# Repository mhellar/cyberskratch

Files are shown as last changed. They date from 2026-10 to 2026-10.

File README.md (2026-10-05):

# CYBERSKRATCH

**A robot DJ on an ESP32-S3.** SAM (the 1982 Software Automatic Mouth) speaks words onto a turntable deck you
scratch, either tempo-synced by holding a pad or by hand with the knob. It also has a Speak & Spell mouth (Talkie LPC) you can bend and freeze, a
hip-hop drum machine, a 16-step sequencer and a rack of voice effects. It runs on a 4x4 keypad, one knob, a
128x128 OLED and a small speaker.

**New in this release:**
- **3D viz engine.** A small polygon renderer (flat-shaded solids, wireframes, painter's sort, glitch post-FX,
  Bayer dithering) drives a VJ view that plays along with the music, and a 3D intro film.
- **Laser-cut case.** A minimal top and bottom plate in 3 mm acrylic, with an engraved legend.

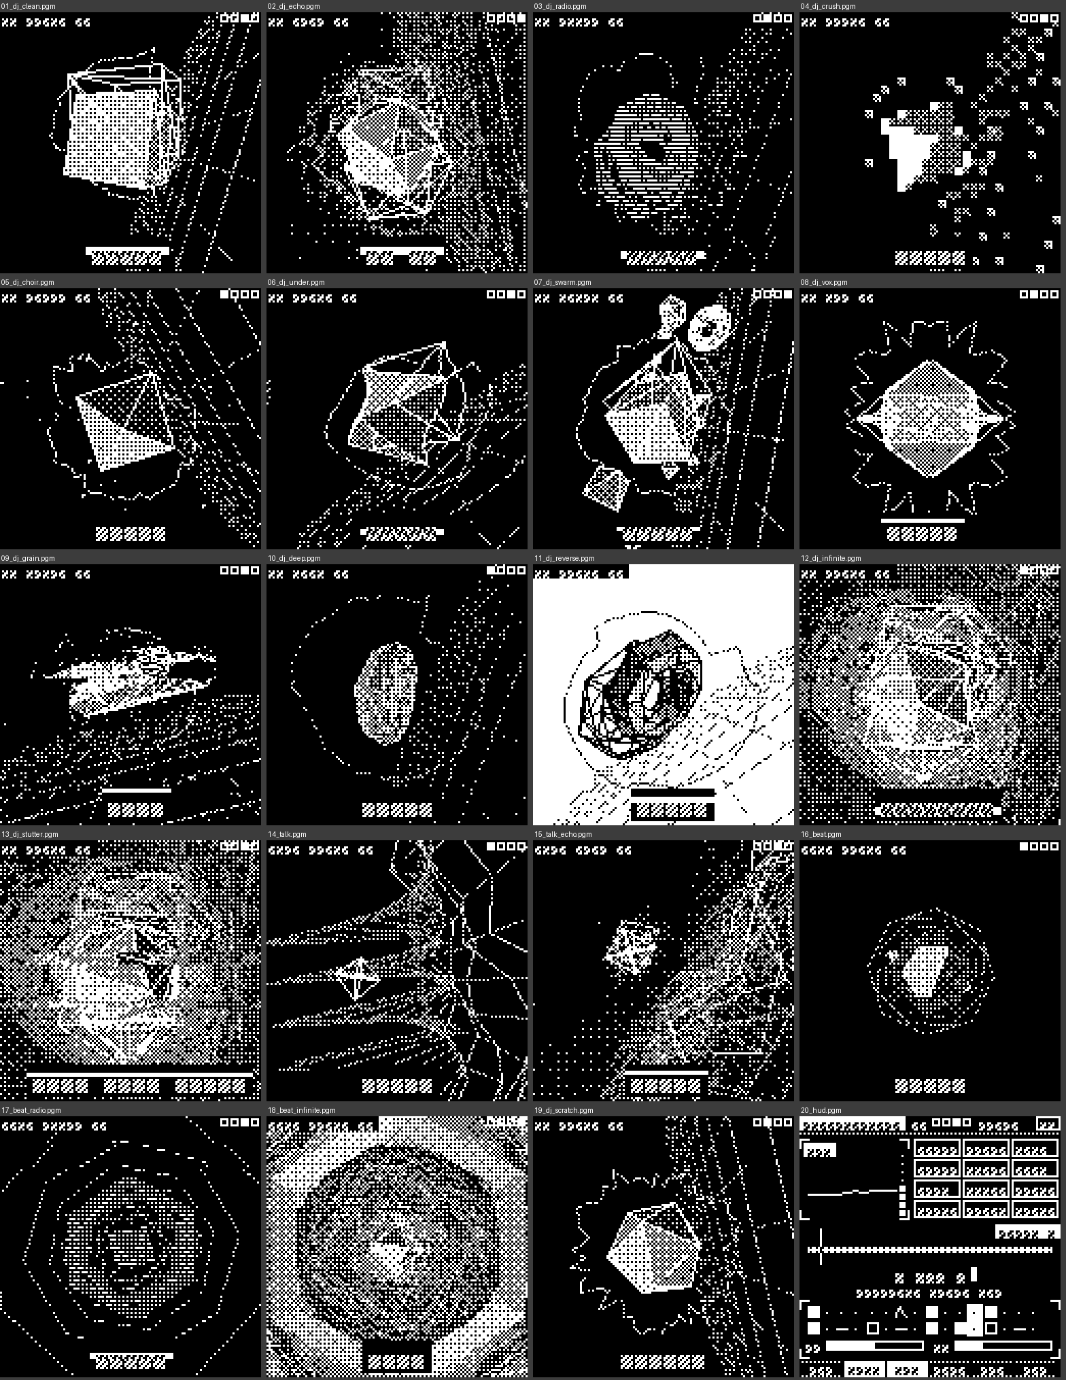
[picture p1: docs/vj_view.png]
VJ view, every mode and FX


| 3D intro | Laser-cut case |
|---|---|
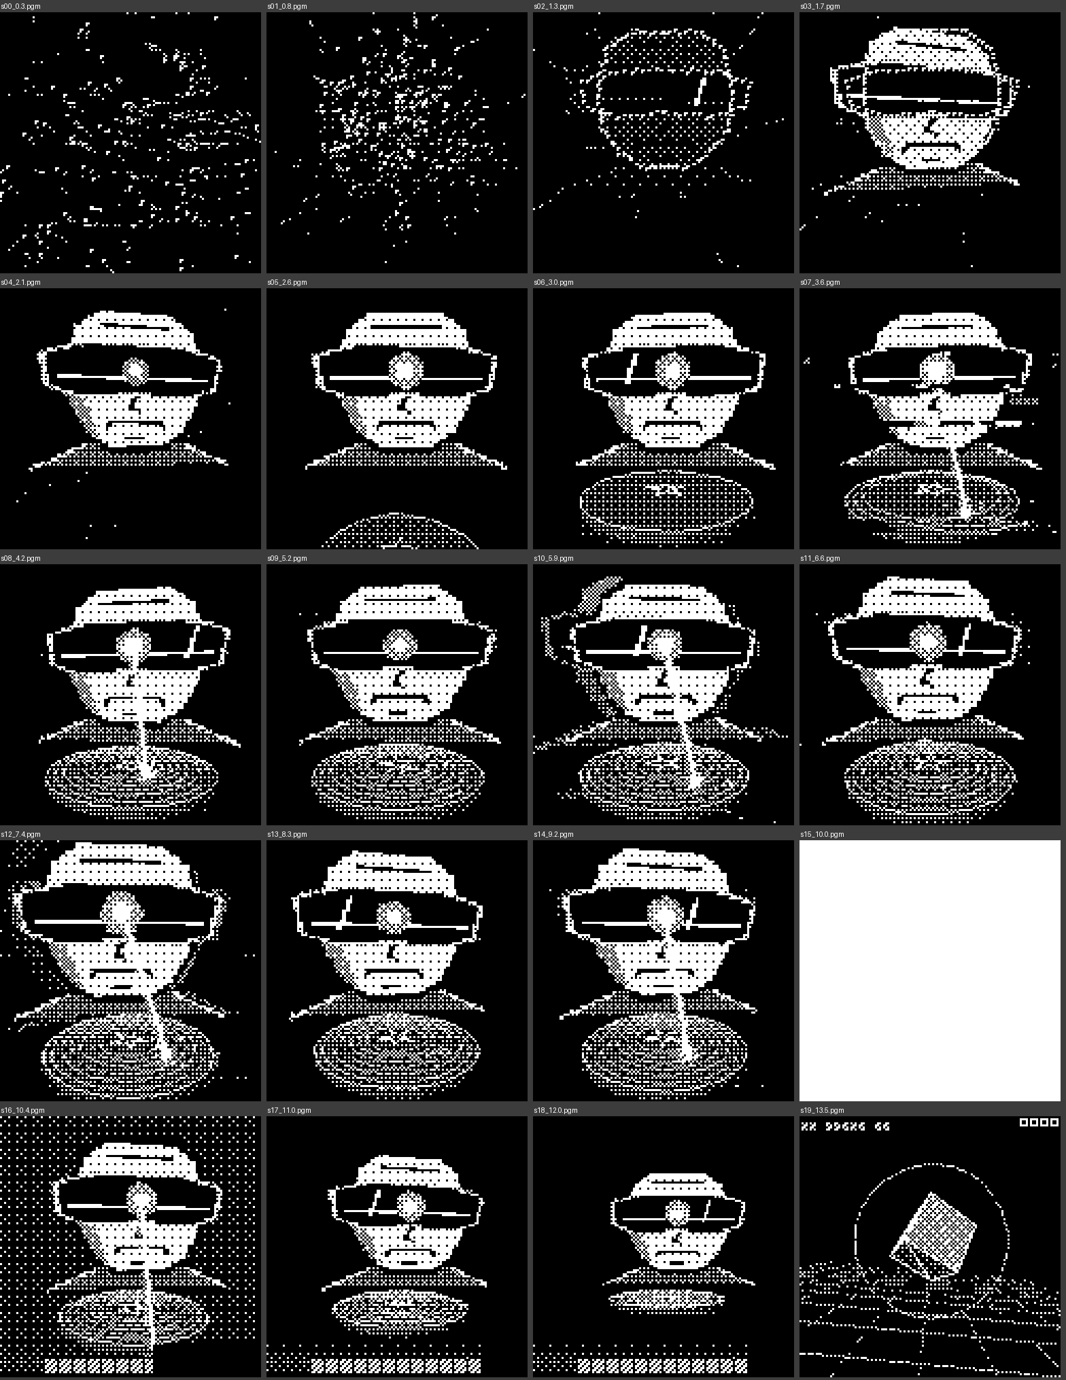
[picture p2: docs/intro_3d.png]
intro
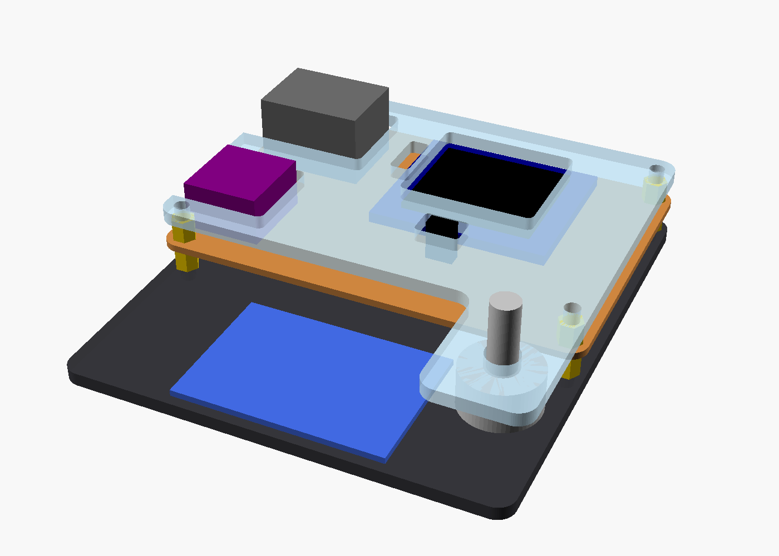
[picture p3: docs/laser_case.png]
case
|  |  |

## What's in here

| Folder | Contents |
|---|---|
| `firmware/cyberskratch_3d/` | The Arduino sketch, with SAM's C core and the Talkie vocabularies bundled alongside |
| `firmware/cyberskratch_3d/host_sim/` | Desktop simulator: runs the real audio engine with g++ and saves VJ frames (see its README) |
| `hardware/laser_case/` | Minimal acrylic case: top plate (cut + engrave), bottom plate, OpenSCAD source, build notes |
| `docs/MANUAL.md` | How to play it |

The board itself (keypad synth rev B, single-sided, CNC-milled) is in the
**blasteroid-megasynth** repo under `hardware/`. CyberSkratch runs on the same board.

## Parts

| Part | Notes |
|---|---|
| ESP32-S3 **SuperMini** with **PSRAM** (4 MB flash / 2 MB PSRAM) | on 2x 1x9 female headers |
| MAX98357A I2S amp breakout + small 4-8 ohm speaker | VIN on 5 V |
| 1.5" 128x128 OLED, **SH1107**, I2C | VCC GND SCL SDA |
| 4x4 tact keypad module (passive matrix, e.g. QYF-JP01) | hangs off the front edge on edge pads |
| 10k pot | on wires, mounted in the case's wing |
| optional TRRS breakout | headphones, wired off the amp |

## Pinout (rev A / rev B board)

| Function | GPIO |
|---|---|
| OLED SDA / SCL | 9 / 8 |
| Amp DIN / BCLK / LRC | 43 (TX) / 44 (RX) / 1 |
| Keypad rows R1-R4 / columns C1-C4 | 2 3 4 5 / 6 7 13 12 |
| Pot wiper / pot high leg | 10 / 11 (driven HIGH as the pot's supply), low leg to GND |

For the full-size DevKitC board (rev C), set `#define BOARD_REV_C 1` at the top of the sketch.
The amp uses the TX/RX pins, so **USB CDC On Boot must be Enabled** (serial goes over native USB).

## Build the firmware

1. Arduino IDE (or arduino-cli) with the **ESP32 core 3.x** and the **U8g2** library.
2. Board settings: **ESP32S3 Dev Module**, **USB CDC On Boot: Enabled**, **PSRAM: enabled**
   (a DevKitC-1 N8R8 needs PSRAM: OPI).
   arduino-cli FQBN: `esp32:esp32:esp32s3:CDCOnBoot=cdc,PSRAM=enabled`
3. Open `firmware/cyberskratch_3d/cyberskratch_3d.ino` and upload.

## Laser-cut case

Two pieces of 3 mm acrylic, cut on a CO2 laser. The top plate sits 5 mm above the board on M3 standoffs, with
cut-outs around the tall parts and a plain window over the OLED. The pot sits on a wing beside the keypad. The board
stands on 6 mm standoffs on the bottom plate. `hardware/laser_case/README.txt` has the parts list and laser
settings. `top_plate_LASER.svg` is cut + engrave in one file (black fill = engrave, red hairline = cut).

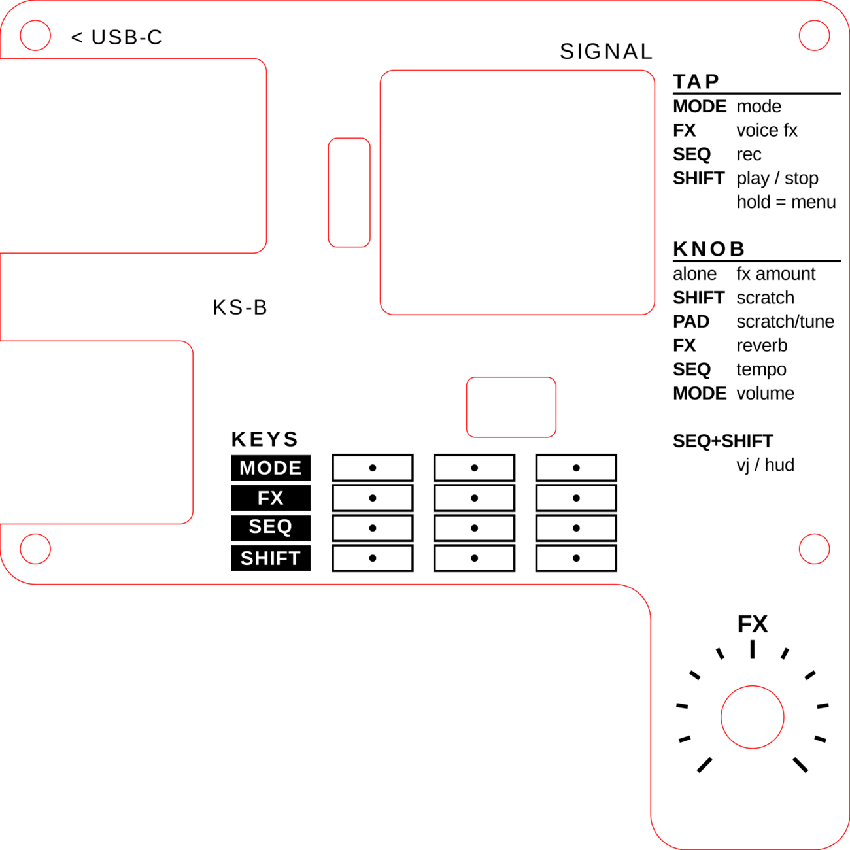
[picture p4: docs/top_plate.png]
top plate


## Fun fact

The TALK mode's robot voice runs the same LPC speech tech as Texas Instruments' Speak & Spell. Its FLIGHT, ALPHA
and SKY word banks come from early-80s TI talking-chip ROMs (VM61002-5), whose vocabulary was built for cockpits
and air traffic control: AUTOPILOT, RADAR, STALL, MAYDAY, LANDING GEAR, the NATO alphabet, weather calls, even
MIG and INTRUDER. Talkie's own notes call it "a very military bias".

## Credits

- **SAM**: Software Automatic Mouth (Don't Ask Software, 1982). C port by Sebastian Macke, ESP8266/ESP32
  version by Earle F. Philhower III ([ESP8266SAM](https://github.com/earlephilhower/ESP8266SAM)).
- **Talkie**: Peter Knight's Speak & Spell LPC decoder and vocabularies, extended by Armin Joachimsmeyer.
- **U8g2** by olikraus.
- The word lexicon nods to Norbert Wiener's *Cybernetics* (kybernetes = steersman).

## License

GPL-3.0 (SAM and the Talkie vocabularies are GPL v3, so the whole sketch is too). See `LICENSE`.

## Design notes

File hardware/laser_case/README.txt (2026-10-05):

CYBERSKRATCH MINIMAL CASE - keypad_synth_revB, two pieces of 3 mm acrylic (top + bottom plate), CO2 cut
=====================================================================================
top_plate.svg / .dxf     96 x 96 mm: covers the main board plus a pot wing beside the keypad
bottom_plate.svg / .dxf  96 x 104 mm: one rectangle under the board + keypad + wing, 4 holes under the board's
top_plate_LASER.svg      top plate with the ENGRAVE layer: black fill = engrave, red hairline = cut (engrave first,
                         then cut). top_engrave.dxf = the legend alone. Preview: top_plate_LASER.png
(true mm, red hairline = cut). Source top_plate.scad: part="plate" / "bottom" to export, "preview" for preview.png.

WHAT IT DOES
  Sits 5 mm above the main board on M3 standoffs at the board's 4 holes, just above the OLED glass (4 mm).
  Cut-outs: SuperMini + its sockets and the amp (both open to the left edge, so USB-C and speaker wires get out),
  a plain OLED window over the display, a slot over the OLED header pins, and the pot wire header.
  The pot mounts in the wing (front right, beside the keypad): its body hangs into open air there.
  The keypad stays uncovered, and the TRRS breakout stays loose on its wires.

BUY / HAVE
  4x M3 standoffs 5 mm (board top -> top plate), 4x M3 standoffs 6 mm (bottom plate -> board bottom),
  8x M3x6 screws (4 into the top plate, 4 up through the bottom plate), 4 rubber feet under the bottom plate.
  The keypad sits 5.8 mm below the board bottom, so with 6 mm standoffs it rests on the bottom plate
  (a strip of foam tape under it stops it rattling). 12.6 mm free under the pot wing for the pot body.

CHECK FIRST (1:1 paper print on the board)
  Positions come from the KiCad footprints. Check: SuperMini + amp cut-outs clear their sockets, the OLED window
  sits on the glass, and the header slot is over the OLED's 4 pins (if those pins stick up more than 4.5 mm,
  use 6 mm standoffs on top). The pot wires leave their header upwards and loop over the plate to the pot.
CO2: cut ~10-15 mm/s, 70-90 %, 1 pass, air assist, keep the film on.
     Engrave (peel the film off first) ~300 mm/s, 15-25 %, 0.1 mm interval. Cast acrylic engraves frosty white.
     Clear acrylic: mirror the engrave layer and burn it on the underside - reads through, never wears.

LEGEND (engraved, no logo): TAP / KNOB key table right of the screen, SIGNAL over the screen, FX dial around the pot,
  "< USB-C" by the SuperMini slot, and a KEYS map in front of the plate's front edge: its 4 columns sit straight
  behind the real keypad columns, left column = MODE / FX / SEQ / SHIFT (back row -> front row).

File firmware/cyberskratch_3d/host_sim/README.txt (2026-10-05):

Desktop preview of the VJ view. Build (Git Bash, here):
  cp ../cyberskratch_3d.ino game.inc; cp ../Vocab_* .; g++ -O1 -std=gnu++17 -I. -o cs.exe main.cpp Vocab_*.cpp; mkdir -p out; ./cs.exe
Runs the real audio engine; the I2S hook advances time and draws a frame every 50 ms. SHOTS[] in main.cpp = one frame per mode / FX.

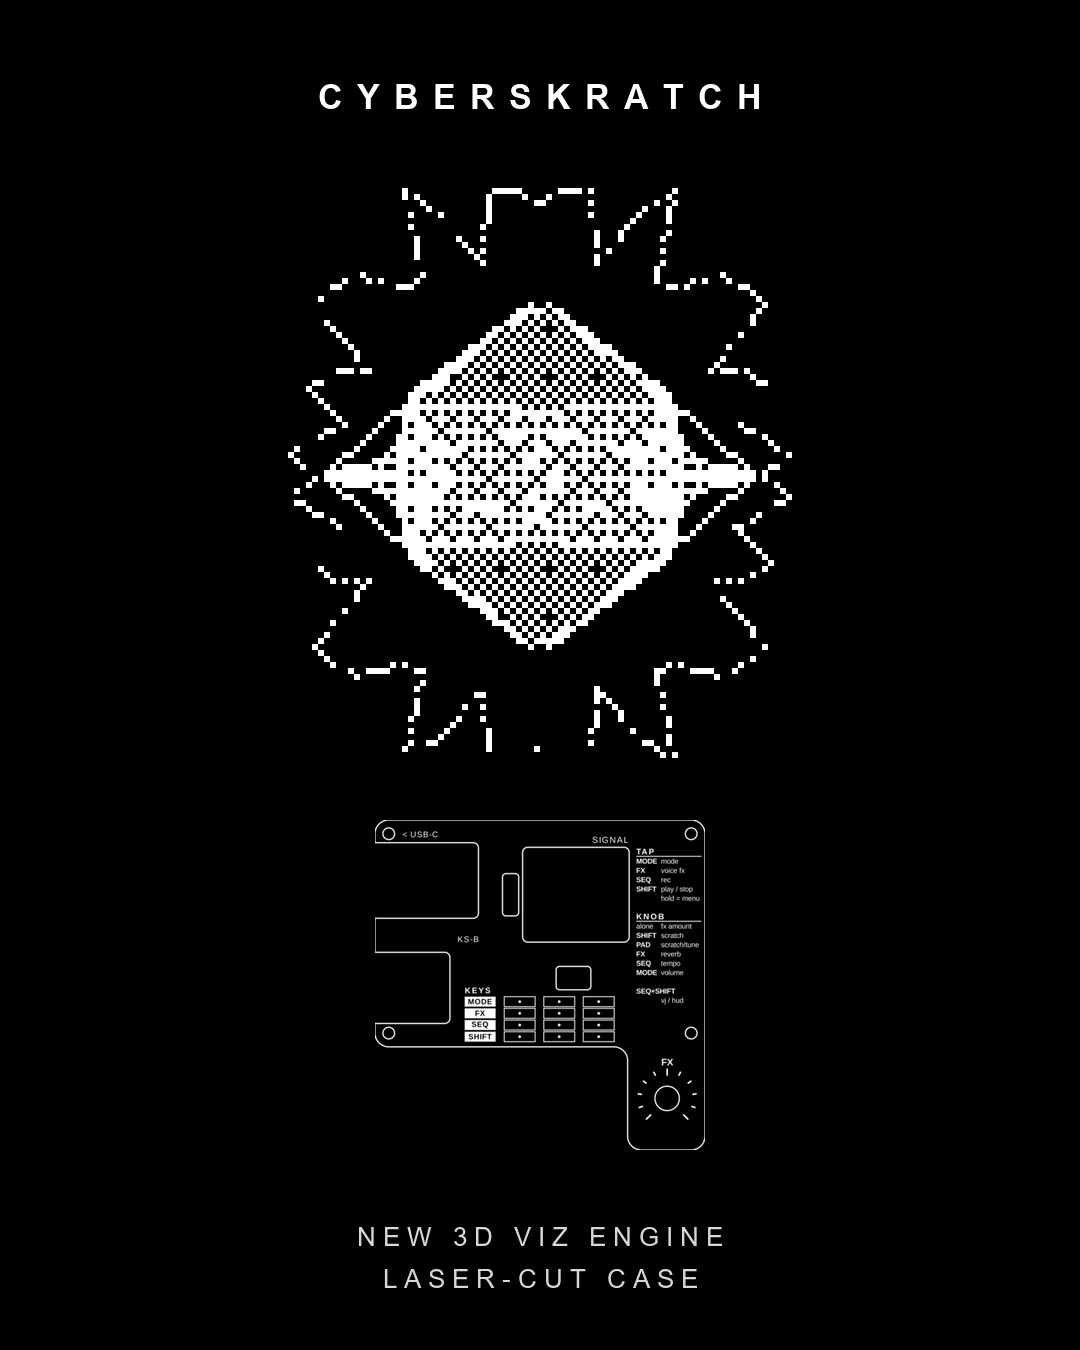
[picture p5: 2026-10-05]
docs/insta_teaser.png

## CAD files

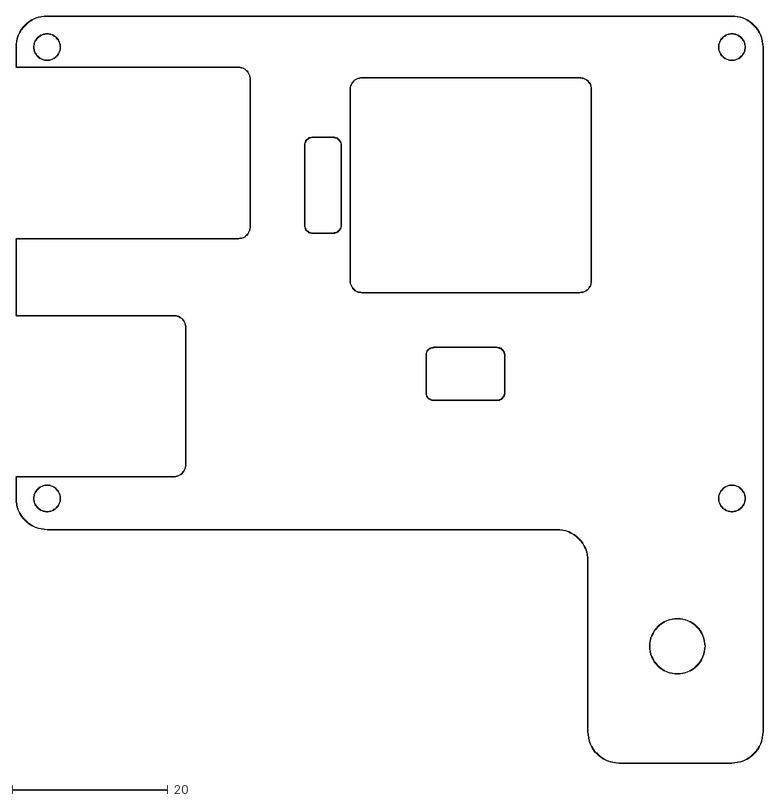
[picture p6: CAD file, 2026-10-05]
hardware/laser_case/top_plate.dxf
96.0 x 96.0

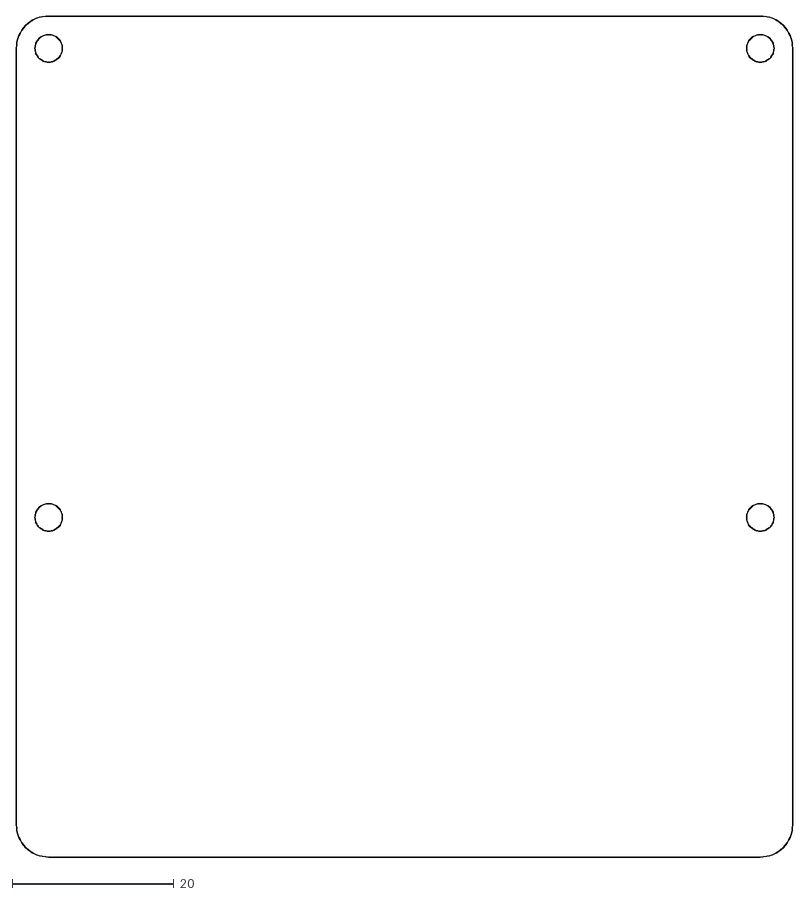
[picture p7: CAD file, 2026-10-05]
hardware/laser_case/bottom_plate.dxf
96.0 x 104.0

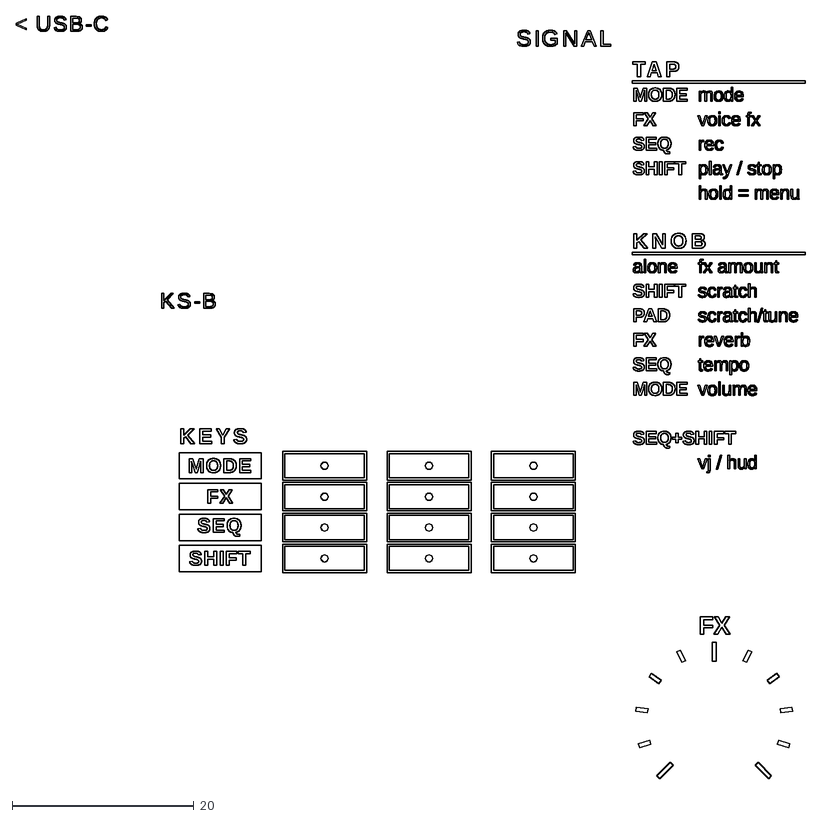
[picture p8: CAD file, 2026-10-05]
hardware/laser_case/top_engrave.dxf
86.9 x 84.0

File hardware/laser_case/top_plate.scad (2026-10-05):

// CYBERSKRATCH minimal top plate - keypad_synth_revB. ONE piece of 3 mm acrylic (CO2 cut), sitting 5 mm above the
// main board on M3 standoffs at the board's 4 holes. Cut-outs around everything taller than the OLED glass,
// a plain window over the OLED (no chimney), and a wing beside the keypad for the pot (open air under it).
//
// Coordinates = case coordinates (X left->right, Y front(keypad)->back, origin = front-left corner of the main
// board, top view). Part positions read from keypad_synth_revB.kicad_pcb (footprint pads / outlines).
// BOTTOM plate: one more 3 mm piece under the board + keypad; the board stands on it on 6 mm M3 standoffs, the
// keypad (5.8 mm below the board bottom) rests on it.
// part = "plate" | "bottom" | "engrave" (2D, export) | "preview" (3D with ghost parts)
// ENGRAVE = legend for the top plate (same content as ../overlay.scad, re-laid-out around the cut-outs). No logo.
part = "preview";
$fn = 64;

BW = 96;  BH = 66;  T = 3;  above = 5;         // plate thickness, gap board top -> plate underside (standoffs)
below = 6;                                     // standoffs board bottom -> bottom plate top
holes = [[4,4],[92,4],[4,62],[92,62]];
c = 1.0;                                       // clearance around parts

kp = [24.8, -36.0, 70.9, 0];                   // keypad module (case X/Y), hangs 6 mm lower
mcu = [3.0, 38.4, 29.1, 58.4];                 // SuperMini + its socket pads, USB-C at the left edge
amp = [1.4, 7.8, 20.8, 26.5];                  // MAX98357A on its socket (bottom kept clear of the H4 standoff)
potcon = [53.7, 17.6, 61.8, 22.4];             // 3-pin pot wire header (pads at X 55.2 57.7 60.3, Y 20.0)
oled_glass = [43.45, 30.96, 73.45, 57.56];     // OLED display area (F.Fab inner rect)
oled_hdr = [37.9, 38.9, 41.0, 49.6];           // OLED header pins (X 39.45, Y 40.4..48.1)
wing = [73.5, -30, BW, 0];                     // pot wing beside the keypad
pot = [85.0, -15.0];  pot_hole = 7.1;          // pot thread 6.5 mm

module rrect(x0, y0, x1, y1, r) { translate([x0+r, y0+r]) offset(r=r) square([x1-x0-2*r, y1-y0-2*r]); }
module box(b, g=c, r=1) { rrect(b[0]-g, b[1]-g, b[2]+g, b[3]+g, r); }
module to_left(b, g=c) { rrect(-5, b[1]-g, b[2]+g, b[3]+g, 1.5); }   // cut-out open to the left edge

module outline() {
    rrect(0, 0, BW, BH, 4);
    rrect(wing[0], wing[1], wing[2], wing[3] + 8, 4);                // wing (its back corners hide inside the board)
    translate([wing[0] - 4, -4]) difference() { square([4.01, 4.01]); circle(r=4); }   // inside corner fillet
}

module plate() {
    difference() {
        outline();
        for (h = holes) translate(h) circle(d=3.4);
        to_left(mcu);
        to_left(amp);
        box(potcon, 1.0, 1);
        box(oled_glass, 0.5, 1.5);
        box(oled_hdr, 0.8, 1);
        translate(pot) circle(d=pot_hole);
    }
}

module bottom() {
    difference() {
        rrect(0, kp[1] - 2, BW, BH, 4);            // board + keypad + wing footprint as one rectangle
        for (h = holes) translate(h) circle(d=3.4);
    }
}

// ---------- engrave legend ----------
font  = "Liberation Sans:style=Bold";
fontr = "Liberation Sans";
module tick(a, r0, r1, w=0.45) { rotate(a) translate([-w/2, r0]) square([w, r1-r0]); }
module ring2d(w=0.25) { difference() { offset(delta=w/2) children(); offset(delta=-w/2) children(); } }

// quick-reference table in the free strip right of the OLED (from overlay.scad / cyberskratch_3d)
kt_x = 76.0;  kt_x2 = 83.2;  kt_y = 56.0;  kt_lh = 2.7;  kt_sz = 1.5;  kt_w = 19.0;
kt_rows = [
    ["#", "TAP"], ["MODE", "mode"], ["FX", "voice fx"], ["SEQ", "rec"], ["SHIFT", "play / stop"], ["~", "hold = menu"],
    [" ", ""],
    ["#", "KNOB"], ["-", "fx amount"], ["SHIFT", "scratch"], ["PAD", "scratch/tune"], ["FX", "reverb"],
    ["SEQ", "tempo"], ["MODE", "volume"],
    [" ", ""],
    ["=", "SEQ+SHIFT"], ["~", "vj / hud"],
];
module key_table() {
    for (i = [0:len(kt_rows)-1]) {
        r = kt_rows[i];  y = kt_y - i*kt_lh;
        if (r[0] == "#") {
            translate([kt_x, y]) text(r[1], size=1.7, font=font, spacing=1.25);
            translate([kt_x, y-0.7]) square([kt_w, 0.25]);
        } else if (r[0] == "~") translate([kt_x2, y]) text(r[1], size=kt_sz, font=fontr);
        else if (r[0] == "=") translate([kt_x, y]) text(r[1], size=kt_sz, font=font);
        else if (r[0] == "-") { translate([kt_x, y]) text("alone", size=kt_sz, font=fontr);
                                translate([kt_x2, y]) text(r[1], size=kt_sz, font=fontr); }
        else if (r[0] != " ") { translate([kt_x, y]) text(r[0], size=kt_sz, font=font);
                                translate([kt_x2, y]) text(r[1], size=kt_sz, font=fontr); }
    }
}

// key map in the front band, its columns straight behind the real keypad columns; left column named
km_cols = [30.6, 42.1, 53.6, 65.1];  km_w = 9.0;  km_h = 2.9;  km_top = 14.6;
km_names = ["MODE", "FX", "SEQ", "SHIFT"];      // back row (nearest the board) -> front row
module key_map() {
    translate([km_cols[0] - km_w/2, km_top + 1.0]) text("KEYS", size=1.7, font=font, spacing=1.25);
    for (r = [0:3], k = [0:3]) {
        cx = km_cols[k];  y1 = km_top - r * (km_h + 0.5);  y0 = y1 - km_h;
        if (k == 0) {
            translate([cx - km_w/2, y0]) square([km_w, km_h]);                     // filled cell...
        } else ring2d() translate([cx - km_w/2, y0]) square([km_w, km_h]);
        if (k > 0) translate([cx, (y0 + y1) / 2]) circle(d=0.8, $fn=16);
    }
}
module key_map_text() {                                                           // ...with the name knocked out
    for (r = [0:3]) translate([km_cols[0], km_top - r * (km_h + 0.5) - km_h/2])
        text(km_names[r], size=1.6, font=font, halign="center", valign="center", spacing=1.1);
}

module engrave() {
    // pot dial on the wing: 11 ticks over 270 deg, ends + centre long
    translate(pot) {
        for (i = [0:10]) tick(135 - i*27, (i==0||i==5||i==10) ? 6.6 : 7.4, 8.7);
        translate([0, 9.6]) text("FX", size=2.0, font=font, halign="center");
    }
    translate([oled_glass[2] + 0.5, oled_glass[3] + 1.8]) text("SIGNAL", size=1.8, font=fontr, halign="right", spacing=1.2);
    translate([8.0, 61.0]) text("< USB-C", size=1.7, font=fontr, spacing=1.15);
    translate([24.0, 30.5]) text("KS-B", size=1.7, font=fontr, spacing=1.2);
    key_table();
    difference() { key_map(); key_map_text(); }
}

if (part == "plate") plate();
if (part == "engrave") intersection() { engrave(); plate(); }
if (part == "bottom") bottom();
if (part == "preview") {
    color("peru") translate([0, 0, -1.6]) linear_extrude(1.6) rrect(0, 0, BW, BH, 4);
    color("royalblue") translate([kp[0], kp[1], -7.4]) cube([kp[2]-kp[0], kp[3]-kp[1]-4, 1.4]);
    color("dimgray") translate([mcu[0]+1, mcu[1]+1, 0]) cube([mcu[2]-mcu[0]-2, mcu[3]-mcu[1]-2, 16.5]);
    color("purple") translate([amp[0]+1, amp[1], 0]) cube([amp[2]-amp[0]-2, amp[3]-amp[1], 11]);
    color("navy") translate([37.7, 26.3, 0]) cube([40.9, 35.8, 2.5]);
    color("black") translate([oled_glass[0], oled_glass[1], 2.5]) cube([30, 26.6, 1.5]);
    color("black") translate([potcon[0]+1, potcon[1]+1, 0]) cube([potcon[2]-potcon[0]-2, 3, 9]);
    for (h = holes) color("gold") translate([h[0], h[1], 0]) cylinder(d=5.5, h=above, $fn=6);
    color("silver") translate([pot[0], pot[1], above - 9]) cylinder(d=17, h=9);   // 12.6 mm free under the wing (down to the bottom plate)
    color("silver") translate([pot[0], pot[1], above]) cylinder(d=6, h=T + 12);
    color([0.75, 0.88, 0.95, 0.6]) translate([0, 0, above]) linear_extrude(T) plate();
    color("white") translate([0, 0, above + T]) linear_extrude(0.05) intersection() { engrave(); plate(); }
    for (h = holes) color("gold") translate([h[0], h[1], -1.6 - below]) cylinder(d=5.5, h=below, $fn=6);
    color([0.2, 0.2, 0.22, 0.9]) translate([0, 0, -1.6 - below - T]) linear_extrude(T) bottom();
}

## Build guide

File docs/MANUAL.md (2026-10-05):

# CYBERSKRATCH manual

## The controls

```
   [MODE ] [ pad 0 ] [ pad 1 ] [ pad 2 ]      <- back row (nearest the screen)
   [FX   ] [ pad 3 ] [ pad 4 ] [ pad 5 ]
   [SEQ  ] [ pad 6 ] [ pad 7 ] [ pad 8 ]
   [SHIFT] [ pad 9 ] [ pad 10] [ pad 11]      <- front row
```

The **left column** keys are modifiers: **tap** one for its quick action, **hold** one and the screen shows what the
12 pads do while you hold it. The **knob** is the pot on the case's wing.

## Turning it on

Plug in USB-C. The intro film plays: a 3D scene where the cyclops sits behind the decks, the platter rises, the
laser cuts the grooves and the name gets scratched in. Then you land in the **VJ view** in DJ mode.

- **MODE + SHIFT** held ~1 s replays the intro (with credits).
- **SEQ + SHIFT** held ~0.6 s switches between the **VJ view** (3D visuals) and the classic **HUD** (scope, deck,
  sequencer lanes). The hold menus show in both.

## The three modes (tap MODE to step through)

| Mode | The 12 pads | Tap | Hold |
|---|---|---|---|
| **DJ** | 24 SAM words in two pages of 12 | say the word | tempo-synced turntable scratch (the style is on the SHIFT menu) |
| **TALK** | 12 Speak & Spell words (4 banks) | say the word | freeze the mouth on one frame, humming the chord |
| **BEAT** | 12 drums: KICK SNARE CLAP / HAT OPEN RIM / TOM-L TOM-H 808 / COWBL ZAP CRASH | hit | roll |

## Modifier keys

| Key | Tap | Hold + pad |
|---|---|---|
| **MODE** | next mode (DJ > TALK > BEAT) | modes, word page, volume, talk bank, chord progression, robot voice, replay |
| **FX** | next voice FX | CLEAN CRUSH ECHO RADIO GRAIN SWARM DEEP VOX CHOIR, plus STUTTER / REVERSE / TAPE |
| **SEQ** | record on / off | play, groove, auto, BPM, mutate, crosstalk, clears, silence |
| **SHIFT** | play / stop | per-mode extras, plus UNDERWATER and INFINITE reverb in every mode |

## The knob

| Hold | Knob does |
|---|---|
| nothing | the current voice FX's main control (pitch, bits, echo feedback, radio tuning, grain density...) |
| SHIFT | **scratch** the current word by hand, like a record under your fingers |
| a pad | scratch **that** word (DJ / TALK) or tune that drum (BEAT) |
| FX | SPACE: from dry and close to a huge, long reverb |
| SEQ | tempo |
| MODE | volume |

The knob locks when you let go of it: only a real turn wakes it again, so it doesn't drift by itself.

## Recording a loop

1. Tap **SHIFT** to start the sequencer.
2. Tap **SEQ** to switch recording on.
3. Play words, scratches and drums: they're quantized into the 16 steps.
4. Tap **SEQ** again to stop recording. Hold **SEQ** for grooves, BPM, mutate and the clears.

## The VJ view

The visuals react to whatever is playing:

- **DJ:** a solid that changes shape with every word (ico, cube, octa, torus), spun by the record. Scratch it and
  it whips. There's a grid floor, the output scope as a halo around it, and grains fly off as shards.
- **TALK:** the Speak & Spell mouth as a wireframe landscape rolling towards you (the LPC coefficients are the terrain).
- **BEAT:** a tunnel where every drum fires its own ring.
- **Hits:** a kick pulses, a snare slices the picture, a crash flashes white, and a new word shows up as a double image.
- **Each FX has its own look:** ECHO trails, RADIO scanlines, CRUSH big pixels, CHOIR particles, UNDERWATER wobble,
  GRAIN scatter, SWARM clones, DEEP vignette, VOX kaleidoscope, STUTTER freeze-frame, REVERSE negative,
  TAPE smear, INFINITE zoom feedback.

## Headphones

The MAX98357A is a bridge-tied amp. For a TRRS jack, wire tip + ring 1 to OUT+ through ~100 ohm each, and
ring 2 + sleeve to OUT-. **Never** connect the jack to board GND. Keep the volume low (MODE + knob).

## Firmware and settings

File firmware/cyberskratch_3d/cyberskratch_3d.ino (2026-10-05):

/*
  CYBERSKRATCH 3D - CyberSkratch (robodj_keypad, kept untouched) with a VJ view: abstract 3D glitch visuals that play
  along with the music (see "VJ view" below). SEQ + SHIFT held ~0.6 s = switch between the VJ view and the classic HUD.
  Holding MODE / FX / SEQ / SHIFT still shows the pad menu in both views.
  ===========================================================================================================
  ROBO//DJ KEYPAD ("CYBERSKRATCH" on screen) - the handheld Robo DJ grown up for keypad_synth (rev A / B, or rev C)
  A robot DJ: SAM (Software Automatic Mouth) words on a turntable deck you scratch - tempo-synced by holding a pad,
  or by hand with the knob - a Speak & Spell mouth (Talkie LPC) you can bend and freeze, a hip-hop drum machine,
  a 16-step sequencer, and the full Blasteroid effect rack (vocoder, grains, radio, echo, big reverb SPACE...).
  Grown out of s3_handheld_revA/handheld_robodj + blasteroid_megasynth (both left untouched).

  SAM (C core from earlephilhower/ESP8266SAM) and the Talkie LPC vocabularies (Peter Knight / Armin Joachimsmeyer)
  are bundled in this folder; both GPL v3, so this sketch is too.

  KEYPAD (keypad hanging below the board, S1 top-left)
     [MODE ] [ pad 0 ] [ pad 1 ] [ pad 2 ]
     [FX   ] [ pad 3 ] [ pad 4 ] [ pad 5 ]
     [SEQ  ] [ pad 6 ] [ pad 7 ] [ pad 8 ]
     [SHIFT] [ pad 9 ] [ pad 10] [ pad 11]
  Left column: tap for the quick action, HOLD it and the screen shows what the 12 pads do.
     MODE  tap = next mode (DJ > TALK > BEAT)   hold: modes, word page, volume, talk bank, chord prog, robot voice, replay
     FX    tap = next voice FX                  hold: CLEAN CRUSH ECHO RADIO GRAIN SWARM DEEP VOX CHOIR, STUTTER/REVERSE/TAPE
     SEQ   tap = REC on/off                     hold: play, groove, auto, BPM, mutate, crosstalk, clears, silence
     SHIFT tap = PLAY/STOP                      hold: per-mode extras (+ UNDERWATER and INFINITE reverb in every mode)
     MODE + SHIFT held ~1 s = the intro film with credits
  KNOB (the rotary pot)
     alone          = the current voice FX's main control (pitch, bits, echo feedback, radio tuning, grain density...)
     SHIFT + knob   = SCRATCH the current word by hand (SAM or Talkie), like a record under your fingers
     hold a pad + knob = scratch THAT word (DJ / TALK) or tune that drum (BEAT)
     FX + knob      = SPACE: from dry and close to a huge, long reverb
     SEQ + knob     = tempo        MODE + knob = volume
  Pads by mode:
     DJ    24 SAM words in two pages of 12. tap = say it, HOLD = tempo-synced turntable scratch (style on SHIFT)
     TALK  12 Speak & Spell words (4 banks). tap = say it, hold = freeze the mouth on one frame, humming the chord
     BEAT  12 drums (KICK SNARE CLAP / HAT OPEN RIM / TOM-L TOM-H 808 / COWBL ZAP CRASH). hold = roll
  With REC on (and the sequencer playing) words, scratches and drums are quantized into the 16 steps.

  Board: "ESP32S3 Dev Module", USB CDC On Boot: Enabled, PSRAM: enabled
  (arduino-cli FQBN esp32:esp32:esp32s3:CDCOnBoot=cdc,PSRAM=enabled; a DevKitC-1 N8R8 needs PSRAM=opi).
  Libraries: U8g2. ESP32 core 3.x.
*/

#include <Arduino.h>
#include <Wire.h>
#include <U8g2lib.h>
#include <ESP_I2S.h>
#include "esp_dsp.h"
#include "SamData.h"
#include "sam.h"
#include "reciter.h"
#include "Vocab_US_Large.h"
#include "Vocab_AstroBlaster.h"
#include "Vocab_Soundbites.h"

// ---------------- pins: pick the board ----------------
#define BOARD_REV_C 0     // 0 = keypad_synth rev A / rev B (SuperMini), 1 = rev C (full-size ESP32-S3-DevKitC-1)
#if BOARD_REV_C
#define PIN_SDA    9
#define PIN_SCL    10
#define AMP_LRC    12
#define AMP_BCLK   13
#define AMP_DIN    14
#define PIN_RGB    48     // DevKitC v1.0 (v1.1 boards have it on 38)
#define PIN_POT    5      // wiper
#define PIN_POT_HI 4      // driven HIGH: powers the pot's high leg
const int ROW_PINS[4] = {1, 2, 42, 41};
const int COL_PINS[4] = {40, 39, 47, 21};
#else
#define PIN_SDA    9
#define PIN_SCL    8
#define AMP_LRC    1
#define AMP_BCLK   44
#define AMP_DIN    43
#define PIN_RGB    48
#define PIN_POT    10     // wiper
#define PIN_POT_HI 11     // driven HIGH: powers the pot's high leg
const int ROW_PINS[4] = {2, 3, 4, 5};
const int COL_PINS[4] = {6, 7, 13, 12};
#endif

#define STATUS_LOG 0      // 1 = print a status line every 2 s (only needed for debugging)
#define FS     22050      // SAM's native rate
#define INV_FS (1.0f / FS)
#define BLOCK  128

const float VOLS[6] = {0.05f, 0.09f, 0.14f, 0.2f, 0.28f, 0.38f};
volatile int volIdx = 2;

// ---------------- types first (Arduino auto-prototypes) ----------------
struct Word { const char* text; uint32_t off, len; };
struct Voice { const char* name; uint8_t speed, pitch, throat, mouth; };
struct Step { int8_t word; uint8_t src, flags; uint16_t drum; bool skip; };
struct LpcFrame { uint8_t energy, period; int16_t k1, k2; int8_t k[8]; };
struct TalkWord { const char* name; const uint8_t* data; uint32_t first, n; };
struct PercDef { const char* name; uint8_t wave; float f0, f1, ptime, dec, gain, noise, drive; };
struct ModKey { bool down, used; uint32_t tDown; };
struct SVF { float lo = 0, bp = 0; };                 // Chamberlin state-variable filter state
struct Rng {                                         // small deterministic RNG
  uint32_t s;
  explicit Rng(uint32_t seed) : s(seed * 2654435761u + 12345u) {}
  uint32_t next() { s ^= s << 13; s ^= s >> 17; s ^= s << 5; return s; }
  float uni(float a, float b) { return a + (b - a) * (next() & 0xFFFFFF) / 16777216.0f; }
  int range(int a, int b) { return a + (int)(next() % (uint32_t)(b - a)); }
};
struct Grain { int word; float pos, inc, age, len, amp; bool on; };
struct Groove { const char* name; const char* lane[4]; uint8_t drum[4]; };
struct Prog { const char* name; int8_t root[4]; uint8_t q[4]; };
// VJ view (3D glitch visuals)
struct V3 { float x, y, z; };
struct Tri3 { uint8_t a, b, c; };
struct Mesh { V3 v[64]; Tri3 t[128]; uint8_t nv, nt; };
struct PTri { float z; int16_t x[3], y[3]; uint8_t shade, wire; };
struct Ring { float z, rot, size; uint8_t kind; bool on; };
struct Part { float x, y, z; };
volatile uint32_t wordTrig = 0;                     // counts every word the deck / mouth starts (the visuals react)
volatile int trigWord = -1, trigSrc = 0;

enum { M_DJ, M_TALK, M_BEAT, M_COUNT };
const char* MODE_NAMES[] = {"DJ", "TALK", "BEAT"};
enum { K_MODE, K_FX, K_SEQ, K_SHIFT };
const char* MOD_NAMES[] = {"MODE", "FX", "SEQ", "SHIFT"};
enum { SRC_SAM, SRC_TALK };
enum { SF_SCR = 1, SF_REV = 2 };
enum { FX_CLEAN, FX_CRUSH, FX_ECHO, FX_RADIO, FX_GRAIN, FX_SWARM, FX_DEEP, FX_VOX, FX_CHOIR, FX_COUNT };
const char* FX_NAMES[] = {"CLEAN", "CRUSH", "ECHO", "RADIO", "GRAIN", "SWARM", "DEEP", "VOX", "CHOIR"};
const char* FX_KNOB[] = {"PITCH", "BITS", "FEEDBACK", "TUNING", "DENSITY", "SPREAD", "DEPTH", "WET", "BREATH"};
enum { SC_BABY, SC_CHIRP, SC_TRANS, SC_TEAR, SC_FLARE, SC_CRAB, SC_COUNT };
const char* SC_NAMES[] = {"BABY", "CHIRP", "TRANSFORM", "TEAR", "FLARE", "CRAB"};
const char* SC_SHORT[] = {"BABY", "CHIRP", "TRANS", "TEAR", "FLARE", "CRAB"};
enum { DK_PLAY, DK_AUTO, DK_KNOB, DK_FREEZE, DK_SPIN };   // how the deck is moving

const Voice VOICES[] = {
  {"ROBOT", 92, 60, 190, 190}, {"SAM", 72, 64, 128, 128}, {"ELF", 72, 64, 110, 160},
  {"E.T.", 100, 64, 150, 200}, {"STUFFY", 82, 72, 110, 105}, {"OLD LADY", 82, 32, 145, 145},
};
#define NVOICES 6
// two pages of 12 pad words; bank[24..26] = the name and its two halves, cut up in the intro routine
// (spelled for SAM: "SIGHBER SKRATCH")
#define NWORDS 24
#define NAME_WORD 24
#define NAME_A 25
#define NAME_B 26
#define NBANKW 27
Word bank[NBANKW] = {
  // a balanced lexicon (Mark, 10-04): page A = cybernetics, the machine (Norbert Wiener: kybernetes = steersman),
  // page B = mind and wonder, with a little warmth. Picked for sound too: plosives, hiss, long vowels scratch differently.
  // (CYBERNETICS swapped for AUTOMATON - too close to "Dianetics" for comfort)
  // + a little Henry Miller for light (titles and his motto)
  {"AUTOMATON"}, {"FEEDBACK"}, {"ENTROPY"}, {"SIGNAL"}, {"NOISE"}, {"HIGHER STATE"},
  {"HOMEOSTASIS"}, {"INFORMATION"}, {"MESSAGE"}, {"LOOP"}, {"OSCILLATE"}, {"ZERO ONE"},
  {"MEMORY"}, {"PATTERN"}, {"SYNAPSE"}, {"PARADOX"}, {"ECHO"}, {"NEXUS"},
  {"KALEIDOSCOPE"}, {"WONDER"}, {"ALWAYS MERRY AND BRIGHT"}, {"STAND STILL LIKE THE HUMMINGBIRD"}, {"INNER SPACE"}, {"CRYSTALLINE"},
  {"SIGHBER SKRATCH"}, {"SIGHBER"}, {"SKRATCH"},
};

#define NBANKS 5
TalkWord talk[NBANKS][12] = {
  // the Speak & Spell side keeps its machine DNA: these chips spoke for cockpits, radar and test benches
  {{"CONTROL", sp4_CONTROL}, {"INFORMATION", sp4_INFORMATION}, {"FREQUENCY", sp2_FREQUENCY}, {"CIRCUIT", sp2_CIRCUIT},
   {"DEVICE", sp2_DEVICE}, {"SEQUENCE", sp4_SEQUENCE}, {"POSITION", sp2_POSITION}, {"CALIBRATE", sp2_CALIBRATE},
   {"MEASURE", sp2_MEASURE}, {"CONNECT", sp2_CONNECT}, {"AUTOMATIC", sp2_AUTOMATIC}, {"MACHINE", sp2_MACHINE}},
  {{"ONE", sp3_ONE}, {"TWO", sp3_TWO}, {"THREE", sp3_THREE}, {"FOUR", sp3_FOUR},
   {"FIVE", sp3_FIVE}, {"SIX", sp3_SIX}, {"SEVEN", sp3_SEVEN}, {"EIGHT", sp3_EIGHT},
   {"PLUS", sp3_PLUS}, {"MINUS", sp3_MINUS}, {"TIMES", sp3_TIMES}, {"EQUALS", sp3_EQUALS}},
  {{"AUTOPILOT", sp5_AUTOPILOT}, {"VECTORS", sp4_VECTORS}, {"RADAR", sp4_RADAR}, {"APPROACH", sp5_APPROACH},
   {"ALTITUDE", sp5_ALTITUDE}, {"HEADING", sp5_HEADING}, {"CONVERGING", sp5_CONVERGING}, {"TOUCHDOWN", sp5_TOUCHDOWN},
   {"STALL", sp5_STALL}, {"CLIMB", sp5_CLIMB}, {"INBOUND", sp5_INBOUND}, {"FREEDOM", sp5_FREEDOM}},
  {{"ALPHA", sp4_ALPHA}, {"BRAVO", sp4_BRAVO}, {"CHARLIE", sp4_CHARLIE}, {"DELTA", sp4_DELTA},
   {"ECHO", sp4_ECHO}, {"FOXTROT", sp4_FOXTROT}, {"HOTEL", sp4_HOTEL}, {"KILO", sp4_KILO},
   {"NOVEMBER", sp4_NOVEMBER}, {"SIERRA", sp4_SIERRA}, {"WHISKEY", sp4_WHISKEY}, {"ZULU", sp4_ZULU}},
  {{"THUNDERSTORM", sp3_THUNDERSTORM}, {"TURBULENCE", sp3_TURBULANCE}, {"CRYSTALS", sp5_CRYSTALS}, {"VISIBILITY", sp3_VISIBILITY},
   {"OBSCURED", sp3_OBSCURED}, {"UNLIMITED", sp3_UNLIMITED}, {"HAZE", sp3_HAZE}, {"MIST", sp3_MIST},
   {"FREEZING", sp3_FREEZING}, {"ALOFT", sp3_ALOFT}, {"DRIZZLE", sp3_DRIZZLE}, {"GREENWICH", sp3_GREENWICH}},
};
const char* BANK_NAMES[NBANKS] = {"CONTROL", "MATH", "FLIGHT", "ALPHA", "SKY"};

// drum kit. drive > 0 = through softclip after the envelope. W_FM: f0 carrier, f1 ratio, noise = index.
// W_METAL: f0 scales the six 808 cymbal squares.
enum { W_SINE, W_KICK, W_SNR, W_CLAP, W_METAL, W_FM, W_SLAM };
const PercDef PERC[12] = {
  // name     wave     f0     f1     ptime   dec    gain   noise  drive
  {"KICK",  W_KICK,  190,   52,    0.045f, 0.40f, 0.95f, 0.6f,  2.2f},
  {"SNARE", W_SNR,   210,   165,   0.025f, 0.20f, 0.62f, 0.9f,  2.0f},
  {"CLAP",  W_CLAP,  0,     0,     0.01f,  0.16f, 0.72f, 0,     1.6f},
  {"HAT",   W_METAL, 1.6f,  0,     0.01f,  0.035f,0.67f, 0,     0},
  {"OPEN",  W_METAL, 1.6f,  0,     0.01f,  0.28f, 0.60f, 0,     0},
  {"RIM",   W_SNR,   820,   640,   0.006f, 0.035f,0.60f, 0.35f, 1.6f},
  {"TOM-L", W_KICK,  180,   110,   0.07f,  0.38f, 0.75f, 0.3f,  1.4f},
  {"TOM-H", W_KICK,  300,   190,   0.06f,  0.30f, 0.70f, 0.3f,  1.4f},
  {"808",   W_KICK,  110,   50,    0.09f,  1.00f, 0.85f, 0.2f,  1.7f},
  {"COWBL", W_FM,    560,   1.48f, 0.05f,  0.22f, 0.40f, 0.5f,  1.3f},
  {"ZAP",   W_SINE,  2600,  70,    0.025f, 0.18f, 0.55f, 0,     0},
  {"CRASH", W_METAL, 1.0f,  0,     0.01f,  1.10f, 0.58f, 0,     0},
};
enum { D_KICK, D_SNARE, D_CLAP, D_HAT, D_OPEN, D_RIM, D_TOML, D_TOMH, D_808, D_COWBL, D_ZAP, D_CRASH };

// built-in grooves (the sequencer's own drum steps play on top)
const Groove GROOVES[] = {
  {"OFF",      {"................", "................", "................", "................"}, {D_KICK, D_SNARE, D_HAT, D_OPEN}},
  {"BOOM BAP", {"x.......x.x.....", "....x.......x...", "x.x.x.x.x.x.x.x.", "................"}, {D_KICK, D_SNARE, D_HAT, D_OPEN}},
  {"BREAK",    {"x.x.......xx....", "....x..x.x..x..x", "x.x.x.x.x.x.x.x.", "..............x."}, {D_KICK, D_SNARE, D_HAT, D_OPEN}},
  {"ELECTRO",  {"x..x..x...x.....", "....x.......x...", "x.xxx.xxx.xxx.xx", "x.........x....."}, {D_KICK, D_CLAP, D_HAT, D_808}},
  {"HALFTIME", {"x.........x.....", "........x.......", "x.x.x.x.x.x.x.x.", "..............x."}, {D_KICK, D_SNARE, D_HAT, D_OPEN}},
};
#define NGROOVES 5
uint16_t grooveMask[NGROOVES][16];

// vocoder chord progression (one chord per bar)
enum { Q_MAJ, Q_MIN, Q_MAJ7, Q_MIN7, Q_DOM7, Q_SUS4 };
const int8_t QI[6][4] = {{0, 4, 7, -1}, {0, 3, 7, -1}, {0, 4, 7, 11}, {0, 3, 7, 10}, {0, 4, 7, 10}, {0, 5, 7, -1}};
const char* QN[6] = {"", "m", "maj7", "m7", "7", "sus4"};
const char* NOTE[12] = {"C", "C#", "D", "Eb", "E", "F", "F#", "G", "Ab", "A", "Bb", "B"};
const Prog PROGS[] = {
  {"EPIC",  {9, 5, 0, 7},  {Q_MIN, Q_MAJ, Q_MAJ, Q_MAJ}},       // Am F C G
  {"POP",   {0, 7, 9, 5},  {Q_MAJ, Q_MAJ, Q_MIN, Q_MAJ}},       // C G Am F
  {"DREAM", {0, 9, 5, 7},  {Q_MAJ7, Q_MIN7, Q_MAJ7, Q_DOM7}},   // Cmaj7 Am7 Fmaj7 G7
  {"SPACE", {0, 10, 8, 7}, {Q_MAJ, Q_MAJ, Q_MAJ, Q_SUS4}},      // C Bb Ab Gsus4
};
#define NPROGS 4

// Serial log that never blocks: with USB plugged in but no serial monitor open, the USB-CDC TX buffer fills
// and a plain Serial.printf hangs the board. Lines that don't fit are dropped.
void logf(const char* fmt, ...) {
  char b[160];
  va_list ap; va_start(ap, fmt);
  int n = vsnprintf(b, sizeof b, fmt, ap);
  va_end(ap);
  if (n <= 0) return;
  n = min(n, (int)sizeof b - 1);
  if (Serial.availableForWrite() >= n) Serial.write((const uint8_t*)b, n);
}

U8G2_SH1107_PIMORONI_128X128_F_HW_I2C oled(U8G2_R1, U8X8_PIN_NONE, PIN_SCL, PIN_SDA);   // R1 = 90 deg clockwise
I2SClass amp;

// Double buffering: a display task pushes the finished frame over I2C (~50 ms) while loop() draws the next one.
// Both run on core 1: the I2C wait is idle time (on core 0 the audio task slowed the transfer down).
#ifndef HOST_SIM
static uint8_t fbuf[2][128 * 16];
static int drawIdx = 0, sendIdx = 0;
static volatile bool sendBusy = false;
static TaskHandle_t dispHandle = nullptr;
void displayTask(void*) {
  for (;;) {
    ulTaskNotifyTake(pdTRUE, portMAX_DELAY);
    u8x8_t* u = oled.getU8x8();
    for (int r = 0; r < 16; r++) u8x8_DrawTile(u, 0, r, 16, fbuf[sendIdx] + r * 128);
    sendBusy = false;
  }
}
void present() {
  while (sendBusy) vTaskDelay(1);
  sendIdx = drawIdx; sendBusy = true;
  xTaskNotifyGive(dispHandle);
  drawIdx ^= 1;
  oled.getU8g2()->tile_buf_ptr = fbuf[drawIdx];
}
void setupDisplayTask() {
  oled.getU8g2()->tile_buf_ptr = fbuf[0];
  xTaskCreatePinnedToCore(displayTask, "disp", 4096, nullptr, 2, &dispHandle, 1);
}
#else
void present() { oled.sendBuffer(); }
void setupDisplayTask() {}
#endif

void drawFrame();

// =====================================================================
// SAM -> sample pool
// =====================================================================
SamData* samdata;
int8_t* pool = nullptr;
uint32_t poolSize = 0, poolPos = 0;
volatile bool bankBusy = true;
volatile bool nameReady = false;                    // the name words render first
volatile int voiceIdx = 0;
int renderProgress = 0;

static void samByte(void*, unsigned char b) { if (poolPos < poolSize) pool[poolPos++] = (int8_t)((int)b - 128); }

bool sayToPool(const char* text, const Voice& v) {
  char input[256];
  int n = 0;
  for (; text[n] && n < 200; n++) input[n] = toupper((int)text[n]);
  input[n] = 0;
  strcat(input, "[");
  samdata = new SamData;
  if (!samdata) return false;
  EnableSingmode(0);
  SetSpeed(v.speed); SetPitch(v.pitch); SetThroat(v.throat); SetMouth(v.mouth);
  bool ok = TextToPhonemes(input);
  if (ok) { SetInput(input); SAMMain(samByte, nullptr); }
  delete samdata;
  return ok;
}

void renderBank(int vi, bool draw) {
  bankBusy = true; nameReady = false;
  delay(30);
  poolPos = 0;
  for (int step = 0; step < NBANKW; step++) {
    int i = step < 3 ? NAME_WORD + step : step - 3;  // the name first, then the pad words
    renderProgress = step * NWORDS / NBANKW;
    if (draw) drawFrame();
    uint32_t start = poolPos;
    bank[i].off = start; bank[i].len = 0;
    if (poolSize - poolPos < FS / 2) continue;       // pool full: skip the rest
    if (!sayToPool(bank[i].text, VOICES[vi])) { poolPos = start; continue; }
    uint32_t a = start, b = poolPos;                 // trim silence at both ends
    while (a < b && abs(pool[a]) < 4) a++;
    while (b > a && abs(pool[b - 1]) < 4) b--;
    bank[i].off = a; bank[i].len = b > a + 8 ? b - a : 0;
    if (i == NAME_B) nameReady = true;
  }
  renderProgress = NWORDS;
  logf("SAM voice %s: %u bytes\n", VOICES[vi].name, poolPos);
  bankBusy = false;
}

static inline float wordAt(int w, float p) {
  const Word& wd = bank[w];
  if (p < 0 || p >= (float)wd.len - 1) return 0;          // float compare: len 0 must not wrap to 4 billion
  int i = (int)p; float f = p - i;
  float a = pool[wd.off + i], b = pool[wd.off + i + 1];
  return (a + (b - a) * f) * (1.0f / 128.0f);
}

// =====================================================================
// Talkie LPC: words decoded to frames at boot, re-synthesized live (so they can be bent)
// Tables and lattice filter from Talkie (Peter Knight) via ESP8266Audio's AudioGeneratorTalkie.
// =====================================================================
#pragma GCC diagnostic push
#pragma GCC diagnostic ignored "-Wnarrowing"
static const uint8_t tmsEnergy[0x10] = {0x00,0x02,0x03,0x04,0x05,0x07,0x0a,0x0f,0x14,0x20,0x29,0x39,0x51,0x72,0xa1,0xff};
static const uint8_t tmsPeriod[0x40] = {0x00,0x10,0x11,0x12,0x13,0x14,0x15,0x16,0x17,0x18,0x19,0x1A,0x1B,0x1C,0x1D,0x1E,0x1F,0x20,0x21,0x22,0x23,0x24,0x25,0x26,0x27,0x28,0x29,0x2A,0x2B,0x2D,0x2F,0x31,0x33,0x35,0x36,0x39,0x3B,0x3D,0x3F,0x42,0x45,0x47,0x49,0x4D,0x4F,0x51,0x55,0x57,0x5C,0x5F,0x63,0x66,0x6A,0x6E,0x73,0x77,0x7B,0x80,0x85,0x8A,0x8F,0x95,0x9A,0xA0};
static const int16_t tmsK1[0x20] = {0x82C0,0x8380,0x83C0,0x8440,0x84C0,0x8540,0x8600,0x8780,0x8880,0x8980,0x8AC0,0x8C00,0x8D40,0x8F00,0x90C0,0x92C0,0x9900,0xA140,0xAB80,0xB840,0xC740,0xD8C0,0xEBC0,0x0000,0x1440,0x2740,0x38C0,0x47C0,0x5480,0x5EC0,0x6700,0x6D40};
static const int16_t tmsK2[0x20] = {0xAE00,0xB480,0xBB80,0xC340,0xCB80,0xD440,0xDDC0,0xE780,0xF180,0xFBC0,0x0600,0x1040,0x1A40,0x2400,0x2D40,0x3600,0x3E40,0x45C0,0x4CC0,0x5300,0x5880,0x5DC0,0x6240,0x6640,0x69C0,0x6CC0,0x6F80,0x71C0,0x73C0,0x7580,0x7700,0x7E80};
static const int8_t tmsK3[0x10] = {0x92,0x9F,0xAD,0xBA,0xC8,0xD5,0xE3,0xF0,0xFE,0x0B,0x19,0x26,0x34,0x41,0x4F,0x5C};
static const int8_t tmsK4[0x10] = {0xAE,0xBC,0xCA,0xD8,0xE6,0xF4,0x01,0x0F,0x1D,0x2B,0x39,0x47,0x55,0x63,0x71,0x7E};
static const int8_t tmsK5[0x10] = {0xAE,0xBA,0xC5,0xD1,0xDD,0xE8,0xF4,0xFF,0x0B,0x17,0x22,0x2E,0x39,0x45,0x51,0x5C};
static const int8_t tmsK6[0x10] = {0xC0,0xCB,0xD6,0xE1,0xEC,0xF7,0x03,0x0E,0x19,0x24,0x2F,0x3A,0x45,0x50,0x5B,0x66};
static const int8_t tmsK7[0x10] = {0xB3,0xBF,0xCB,0xD7,0xE3,0xEF,0xFB,0x07,0x13,0x1F,0x2B,0x37,0x43,0x4F,0x5A,0x66};
static const int8_t tmsK8[0x08] = {0xC0,0xD8,0xF0,0x07,0x1F,0x37,0x4F,0x66};
static const int8_t tmsK9[0x08] = {0xC0,0xD4,0xE8,0xFC,0x10,0x25,0x39,0x4D};
static const int8_t tmsK10[0x08] = {0xCD,0xDF,0xF1,0x04,0x16,0x20,0x3B,0x4D};
static const int8_t chirp[] = {0x00,0x2a,0xd4,0x32,0xb2,0x12,0x25,0x14,0x02,0xe1,0xc5,0x02,0x5f,0x5a,0x05,0x0f,0x26,0xfc,0xa5,0xa5,0xd6,0xdd,0xdc,0xfc,0x25,0x2b,0x22,0x21,0x0f,0xff,0xf8,0xee,0xed,0xef,0xf7,0xf6,0xfa,0x00,0x03,0x02,0x01};
#pragma GCC diagnostic pop

LpcFrame* lpcFrames = nullptr;
uint32_t lpcCap = 0, lpcUsed = 0;
volatile int talkBank = 0;

struct BitReader {
  const uint8_t* p; uint8_t bit = 0;
  static uint8_t rev(uint8_t a) {
    a = (a >> 4) | (a << 4); a = ((a & 0xcc) >> 2) | ((a & 0x33) << 2); a = ((a & 0xaa) >> 1) | ((a & 0x55) << 1); return a;
  }
  uint8_t get(uint8_t bits) {
    uint16_t data = rev(p[0]) << 8;
    if (bit + bits > 8) data |= rev(p[1]);
    data <<= bit;
    uint8_t v = data >> (16 - bits);
    bit += bits;
    if (bit >= 8) { bit -= 8; p++; }
    return v;
  }
};

// decode one LPC word; out == nullptr just counts frames
uint32_t decodeLpc(const uint8_t* data, LpcFrame* out, uint32_t maxN) {
  BitReader br{data};
  LpcFrame cur = {};
  uint32_t n = 0;
  while (n < maxN) {
    uint8_t e = br.get(4);
    if (e == 0xF) break;
    if (e == 0) cur.energy = 0;
    else {
      cur.energy = tmsEnergy[e];
      uint8_t rep = br.get(1);
      cur.period = tmsPeriod[br.get(6)];
      if (!rep) {
        cur.k1 = tmsK1[br.get(5)]; cur.k2 = tmsK2[br.get(5)];
        cur.k[0] = tmsK3[br.get(4)]; cur.k[1] = tmsK4[br.get(4)];
        if (cur.period) {
          cur.k[2] = tmsK5[br.get(4)]; cur.k[3] = tmsK6[br.get(4)]; cur.k[4] = tmsK7[br.get(4)];
          cur.k[5] = tmsK8[br.get(3)]; cur.k[6] = tmsK9[br.get(3)]; cur.k[7] = tmsK10[br.get(3)];
        }
      }
    }
    if (out) out[n] = cur;
    n++;
  }
  return n;
}
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
void loop() {
  static int renderedVoice = 0;
  if (voiceIdx != renderedVoice && !bankBusy) {
    renderedVoice = voiceIdx;
    renderBank(renderedVoice, true);
    flash(VOICES[renderedVoice].name);
    curWord = okWord(curWord);
    if (mode == M_DJ) deckPlay(curWord, false);
  }
  drawFrame();
  static uint32_t lastLog = 0;
  if (STATUS_LOG && millis() - lastLog > 2000) {
    lastLog = millis();
    logf("t=%lus mode %s fx %s step %d blocks %lu heap %u stackfree %u knob %.2f\n", millis() / 1000,
         MODE_NAMES[mode], FX_NAMES[fx], curStep, (unsigned long)audioBlocks, (unsigned)ESP.getFreeHeap(),
         audioHandle ? (unsigned)uxTaskGetStackHighWaterMark(audioHandle) : 0u, knobVal);
  }
  delay(5);
}

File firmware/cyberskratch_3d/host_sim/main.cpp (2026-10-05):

#include "Arduino.h"
#include <vector>
#include <string>
uint32_t fakeMs = 1000;
SerialC Serial; EspC ESP;
void (*i2sHook)(const int16_t*, size_t) = nullptr;
#include "game.inc"
static bool capture = false; static std::string capName;
void U8G2_SH1107_PIMORONI_128X128_F_HW_I2C::sendBuffer() {
  if (!capture) return;
  capture = false;
  for (int x = 0; x < 128; x++) for (int y = 0; y < 128; y++) px[y * 128 + x] = (raw[(x >> 3) * 128 + 127 - y] >> (x & 7)) & 1;
  FILE* f = fopen(("out/" + capName + ".pgm").c_str(), "wb");
  fprintf(f, "P5 128 128 255\n");
  for (int i = 0; i < 128 * 128; i++) fputc(px[i] ? 255 : 0, f);
  fclose(f);
}
struct Done {};
struct Shot { float at; const char* name; void (*set)(); };
static void base() { fx = FX_CLEAN; underOn = reverseOn = stutterOn = revFreeze = tapeOn = false; vjView = true; }
static Shot SHOTS[] = {
  {1.3f, "01_dj_clean", [] { base(); mode = M_DJ; }},
  {2.3f, "02_dj_echo", [] { base(); fx = FX_ECHO; }},
  {3.3f, "03_dj_radio", [] { base(); fx = FX_RADIO; }},
  {4.3f, "04_dj_crush", [] { base(); fx = FX_CRUSH; }},
  {5.3f, "05_dj_choir", [] { base(); fx = FX_CHOIR; }},
  {6.3f, "06_dj_under", [] { base(); underOn = true; }},
  {7.3f, "07_dj_swarm", [] { base(); fx = FX_SWARM; }},
  {8.3f, "08_dj_vox", [] { base(); fx = FX_VOX; }},
  {9.3f, "09_dj_grain", [] { base(); fx = FX_GRAIN; }},
  {10.3f, "10_dj_deep", [] { base(); fx = FX_DEEP; }},
  {11.3f, "11_dj_reverse", [] { base(); reverseOn = true; }},
  {12.8f, "12_dj_infinite", [] { base(); revFreeze = true; }},
  {13.8f, "13_dj_stutter", [] { base(); stutterOn = true; }},
  {15.3f, "14_talk", [] { base(); mode = M_TALK; }},
  {16.3f, "15_talk_echo", [] { base(); mode = M_TALK; fx = FX_ECHO; }},
  {17.8f, "16_beat", [] { base(); mode = M_BEAT; grooveIdx = 2; }},
  {18.8f, "17_beat_radio", [] { base(); mode = M_BEAT; fx = FX_RADIO; }},
  {19.8f, "18_beat_infinite", [] { base(); mode = M_BEAT; revFreeze = true; }},
  {20.8f, "19_dj_scratch", [] { base(); mode = M_DJ; grooveIdx = 1; }},
  {21.8f, "20_hud", [] { base(); vjView = false; }},
};
static double tms = 0; static size_t blocks = 0; static int shot = 0; static float nextFrame = 0, nextWord = 0;
static void hook(const int16_t*, size_t) {
  blocks++;
  tms += 1000.0 * BLOCK / FS; fakeMs = 1000 + (uint32_t)tms;
  float t = tms / 1000.0f;
  if (t >= nextWord) {                               // something to look at: words keep coming
    nextWord = t + 0.55f;
    if (mode == M_TALK) { talkPlay(random(12), false); curTalk = 0; }
    else if (mode == M_DJ) { int w = randomWord(); if (t > 20.3f) deckAuto(w, 4, random(6)); else deckPlay(w, false); curWord = w; }
  }
  if (t >= nextFrame) {
    nextFrame = t + 0.05f;
    if (shot < (int)(sizeof SHOTS / sizeof SHOTS[0])) {
      Shot& s = SHOTS[shot];
      if (t >= s.at - 0.9f) s.set();
      if (t >= s.at) { capture = true; capName = s.name; shot++; }
    } else throw Done();
    drawFrame();
  }
}
int main() {
  setup();
  renderBank(0, false);
  splashOn = false; playing = true;
  i2sHook = hook;
  try { audioTask(nullptr); } catch (Done&) {}
  printf("frames done, %zu audio blocks\n", blocks);
}
